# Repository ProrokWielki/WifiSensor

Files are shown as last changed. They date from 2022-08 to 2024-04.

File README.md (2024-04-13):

# WiFi Sensor

ESP-12F + bme280 sensor. It measures humidity, temperature and pressure. It communicates using mqtt. When in standby it consumes < 1mA which allows it to work for more then 6 months on one set of batteries.

### what you need
* ESP-12F - or compatible device
* BME280
* LT1129-3.3
* 2x 2xAA in series battery holders
* capacitors and resistors

### 



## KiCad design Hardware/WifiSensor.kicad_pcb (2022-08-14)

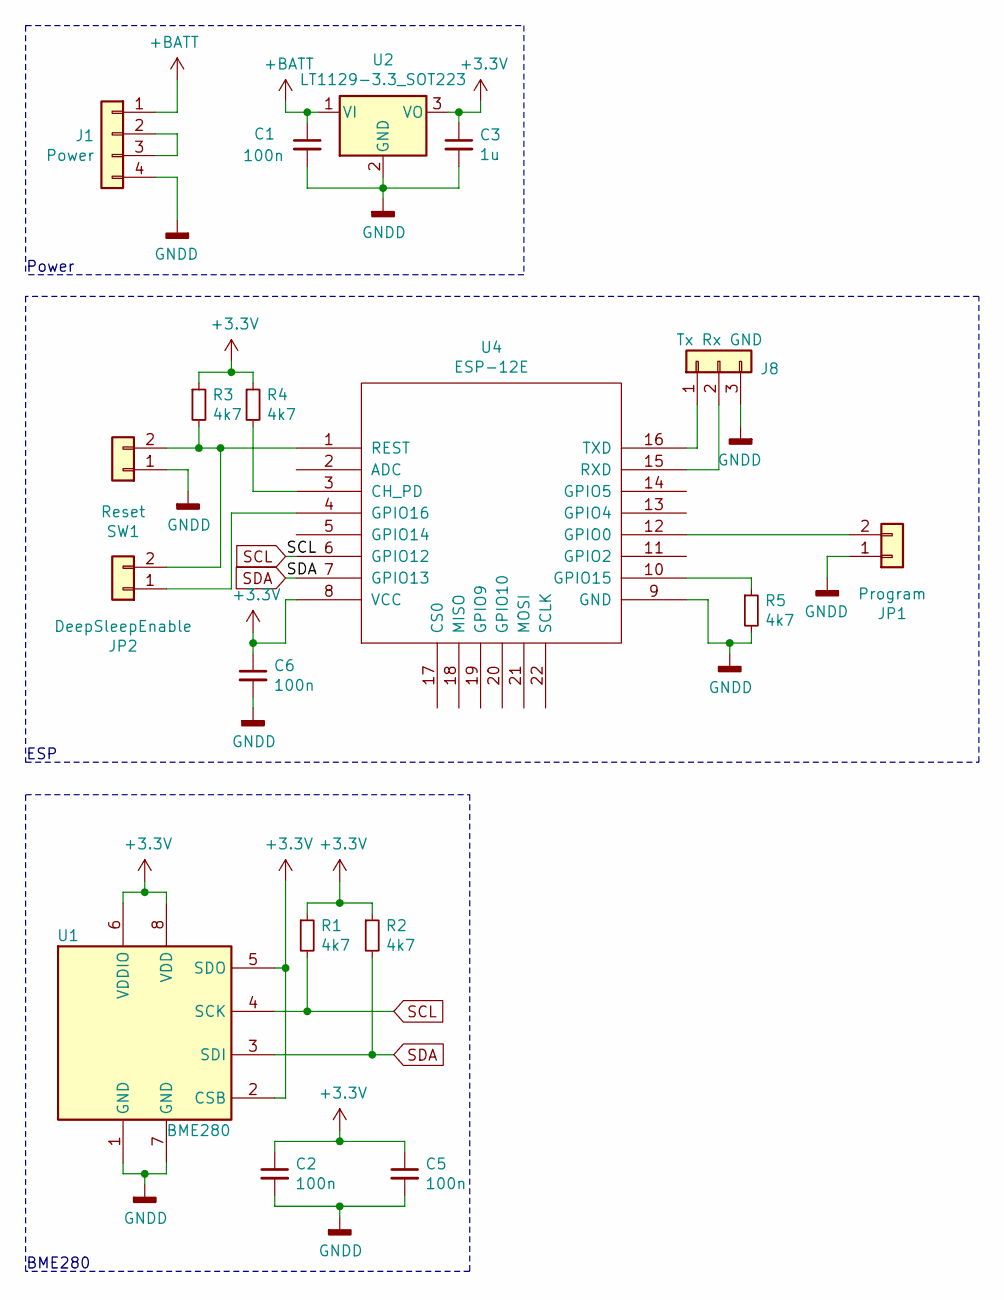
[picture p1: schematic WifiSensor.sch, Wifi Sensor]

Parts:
C1, C2, C5, C6: 100n; 0805
C3: 1u; 0805
J1: Power; Harwin_M20-89004xx_1x04_P2.54mm_Horizontal
J8: Tx Rx GND; Harwin_M20-89003xx_1x03_P2.54mm_Horizontal
JP1: Program; SolderJumper-2_P1.3mm_Open_RoundedPad1.0x1.5mm
JP2: DeepSleepEnable; SolderJumper-2_P1.3mm_Open_RoundedPad1.0x1.5mm
R1, R2, R3, R4, R5: 4k7; 0805
SW1: Reset; SolderJumper-2_P1.3mm_Open_RoundedPad1.0x1.5mm
U1: BME280; Bosch_LGA-8_2.5x2.5mm_P0.65mm_ClockwisePinNumbering
U2: LT1129-3.3_SOT223; SOT-223-3_TabPin2
U4: ESP-12E; ESP-12E_SMD

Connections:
+3V3: C2.1, C3.1, C5.1, C6.1, R1.1, R2.1, R3.1, R4.1, U1.2 (CSB), U1.5 (SDO), U1.6 (VDDIO), U1.8 (VDD), U2.3 (VO), U4.8 (VCC)
+BATT: C1.1, J1.1, U2.1 (VI)
GNDD: C1.2, C2.2, C3.2, C5.2, C6.2, J1.4, J8.3, JP1.1, R5.2, SW1.1, U1.1 (GND), U1.7 (GND), U2.2 (GND), U4.9 (GND)
unnamed: J1.2, J1.3
unnamed: J8.1, U4.16 (TXD)
unnamed: J8.2, U4.15 (RXD)
unnamed: JP1.2, U4.12 (GPIO0)
unnamed: JP2.1, U4.4 (GPIO16)
unnamed: JP2.2, R3.2, SW1.2, U4.1 (REST)
unnamed: R4.2, U4.3 (CH_PD)
unnamed: R5.1, U4.10 (GPIO15)
SCL: R1.2, U1.4 (SCK), U4.6 (GPIO12)
SDA: R2.2, U1.3 (SDI), U4.7 (GPIO13)

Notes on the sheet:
BME280
Power
ESP

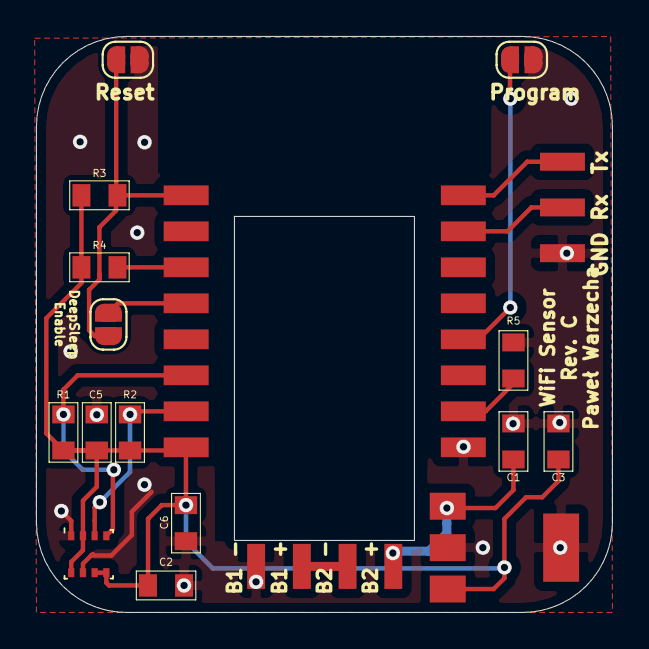
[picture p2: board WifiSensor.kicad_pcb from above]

Board: 2 copper layers, 32.0 x 32.0 mm, 18 parts (0 on the bottom side), 13 nets.

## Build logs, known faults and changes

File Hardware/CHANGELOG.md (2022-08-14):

# Chenglog

### Rev. C - 14.09.2022
* Added jumper to enable deep sleep

### Rev. B - 03.08.2022  
* Changed `U2` from `LM1117-3.3` to `LT1129-3.3` -- smalle quiescent current 

### Rev. A - 02.08.2022
* Initial revison

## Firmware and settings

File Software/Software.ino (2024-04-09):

#include <Arduino.h>

#include <ESP8266WiFi.h>

#include <Wire.h>

#include <ArduinoOTA.h>
#include <PubSubClient.h>

#include <BME280I2C.h>

#include "config/i2c_config.h"
#include "esp_mqtt_helpers/config/mqtt_config.h"
#include "esp_mqtt_helpers/config/wifi_config.h"

#include "esp_mqtt_helpers/helpers/json.h"
#include "esp_mqtt_helpers/helpers/utils.h"

BME280I2C::Settings settings(BME280::OSR_X1, BME280::OSR_X1, BME280::OSR_X1, BME280::Mode_Forced, BME280::StandbyTime_500us, BME280::Filter_Off,
                             BME280::SpiEnable_False, BME280I2C::I2CAddr::I2CAddr_0x77);
BME280I2C bme_(settings);
WiFiClient wifi_;
PubSubClient mqtt_(mqtt::server_ip, mqtt::server_port, wifi_);

constexpr auto topic{"sensor"};
constexpr uint64_t sleep_time = 15 * 60 * 1000 * 1000;

void setup()
{
    Wire.begin(i2c::sda_pin, i2c::scl_pin);

    WiFi.persistent(false);
    WiFi.hostname(wifi::hostname);
    WiFi.mode(WIFI_STA);
    WiFi.begin(wifi::ssid, wifi::password);

    wait_for_initialization([]() { return not(WiFi.status() == WL_CONNECTED); }, 250, []() { ESP.deepSleep(sleep_time); }, 50);
    wait_for_initialization([]() { return not bme_.begin(); }, 250, []() { ESP.deepSleep(sleep_time); }, 10);
    wait_for_initialization([]() { return not(mqtt_.connect(mqtt::client_id)); }, 250, []() { ESP.deepSleep(sleep_time); }, 10);

    float temperature, humidity, pressure;
    bme_.read(pressure, temperature, humidity);
    mqtt_.publish(topic,
                  make_json(std::make_pair("temperature", temperature), std::make_pair("humidity", humidity), std::make_pair("pressure", pressure)).c_str());

    delay(10);

    ESP.deepSleep(sleep_time);
}

void loop()
{
}

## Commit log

2022-08-02 Hardware Rev. A
    [WifiSensor.kicad_pcb, WifiSensor.sch]
2022-08-03 Rev. B
    [WifiSensor.kicad_pcb, WifiSensor.sch]
2022-08-14 Revision C
    [WifiSensor.kicad_pcb, WifiSensor.sch]
2024-04-09 Make WifiSensor more power efficient
    * More frequent wifi status polling
    * bme in force mode
    * shorter delay after publish
    * wifi persitent disabled
    [Software.ino]
